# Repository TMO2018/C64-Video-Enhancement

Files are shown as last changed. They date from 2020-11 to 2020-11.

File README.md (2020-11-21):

# C64 Video Enhancement

The original project can be found here:
https://github.com/c0pperdragon

I've made some changes to the VIC II-Adapter pcb and the rfreplacement pcb.

# VIC II-Adapter (A-VideoBoard c64board)
Rev 3.1 is based on c0pperdragons Rev 3
- Fits better with a 407-board
- Layout for hand soldering (SMD 0805)

# rfreplacment
Rev 6.1 is based on c0pperdragons Rev 6
- Layout for hand soldering (SMD 0805)
- Video connector ist placed in the middle of the hole in the C64-housing

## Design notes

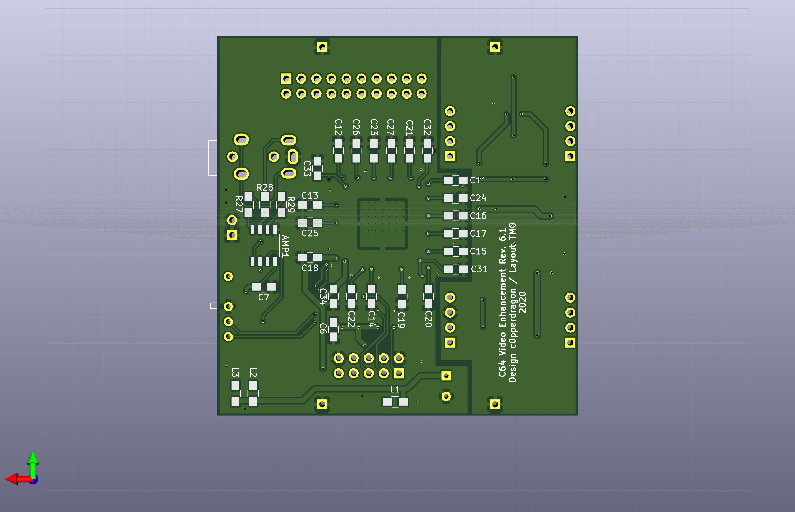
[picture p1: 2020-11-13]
rfreplacement/Rev6_1/pic/rfreplacement_2.jpg

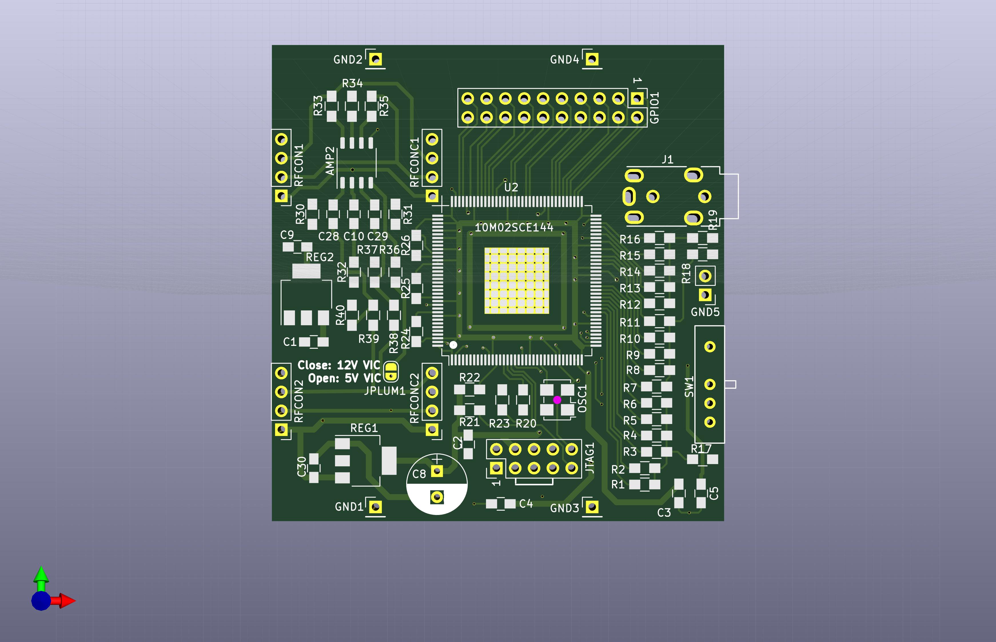
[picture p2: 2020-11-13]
rfreplacement/Rev6_1/pic/rfreplacement_1.jpg

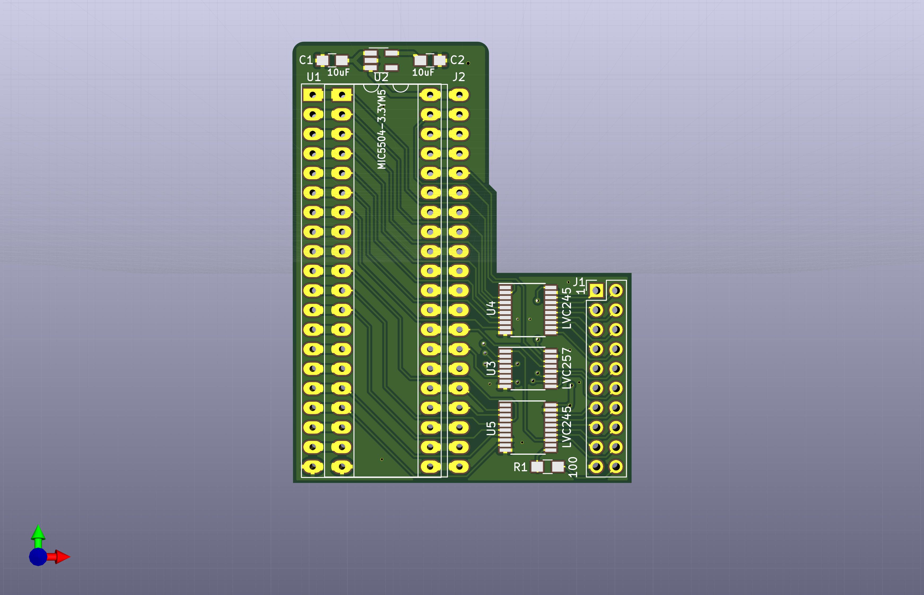
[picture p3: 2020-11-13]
A-VideoBoard c64board/Rev_3_1/pic/c64board_1.jpg

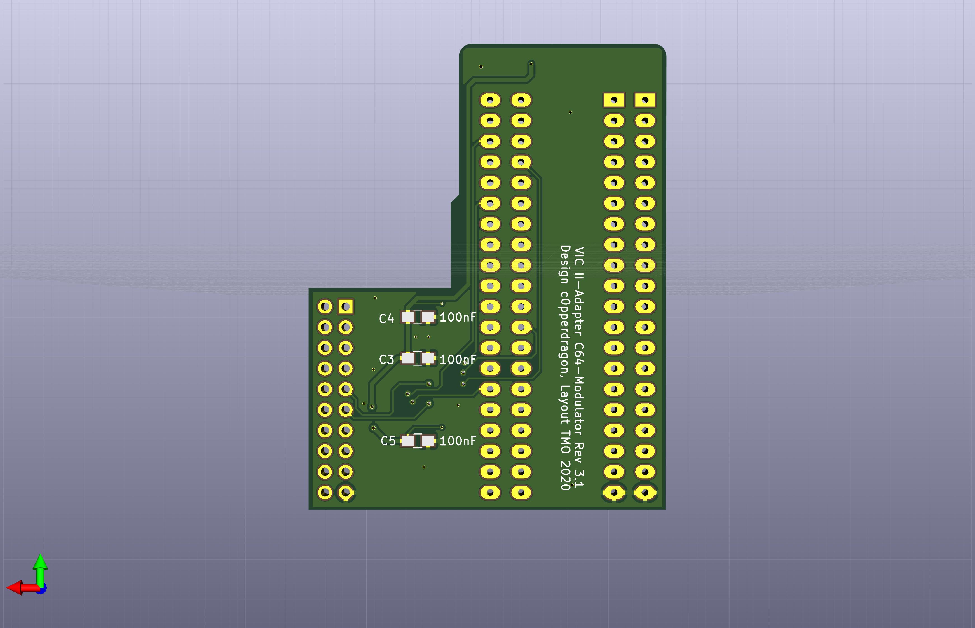
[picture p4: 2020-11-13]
A-VideoBoard c64board/Rev_3_1/pic/c64board_2.jpg

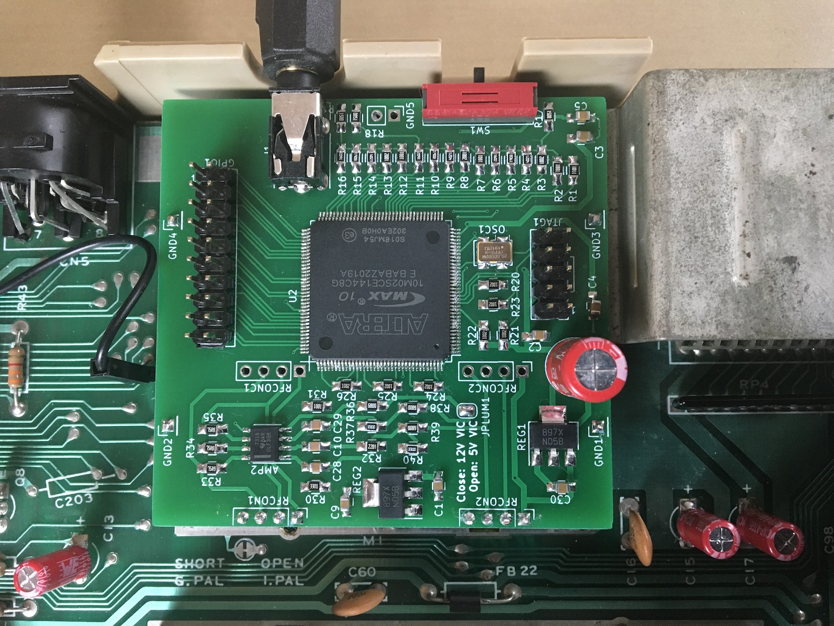
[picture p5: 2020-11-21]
pic/rfreplacement6_1.JPG

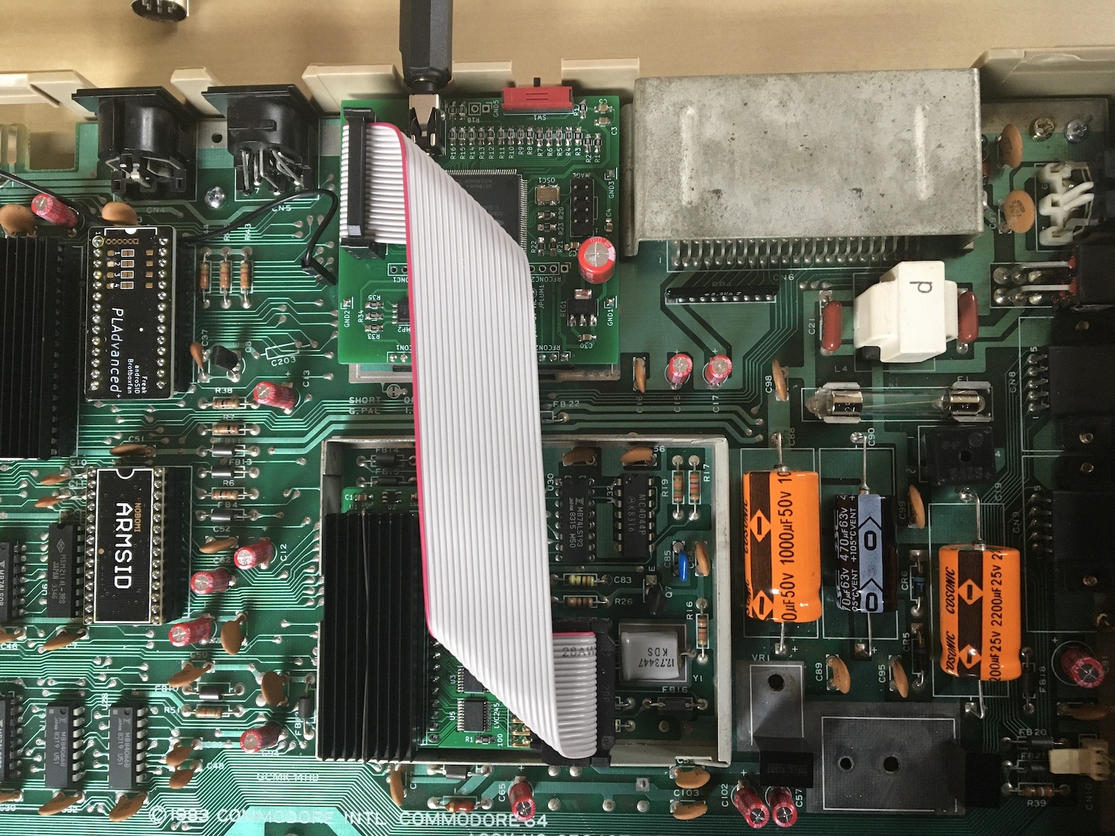
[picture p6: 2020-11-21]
pic/rfreplacement6_1 VICIIboard3_1.jpg

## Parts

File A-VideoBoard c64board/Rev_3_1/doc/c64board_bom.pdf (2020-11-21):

Tabelle1

Manufacturer | Manufacturer Number | Designator | Qty | Description | Case | SMD/ TH | PCB side | Comments
Mill-Max | 111-93-640-41-001000 | U1 | 1 | IC & Component Sockets 40P LONG SOLDER TAIL | | TH | Top | Unusual assembly
Microchip | MIC5504-3.3YM5-TR | U2 | 1 | LDO Voltage Regulators Single 300mA LDO | SOT-23-5 | SMD | Top
Texas Instruments | SN74LVC257APWR | U3 | 1 | Multiplexer | TSSOP-16 | SMD | Top
Texas Instruments | SN74LVC245APWR | U4,U5 | 2 | Bustransceiver Tri-State Octal Bus | TSSOP-20 | SMD | Top
any | | C1,C2 | 2 | Ceramic capacitor 10uF, 10%, 16V | 2012 | SMD | Top
any | | C3,C4,C5 | 3 | Ceramic capacitor 100nF, 10%, 16V | 1608 | SMD | Top
any | | R1 | 1 | Thick film resistor, 100 Ohm, 1% | 2012 | SMD | Top
HARTING | 9181209622 | J1 | 1 | PCB to ribbon cable connector 20P 2 ROW | | TH | Top | Can also be other manufacturer
any | 1 | Ribbon cable, 20 leads, 1,27mm pitch, Length: 13cm | not on PCB
any | 1 | Ribbon cable connector, 20 pins (2x10) female, 2.54mm pitch | not on PCB | gold plated contacts if possible

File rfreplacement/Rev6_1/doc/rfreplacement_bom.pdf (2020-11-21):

Tabelle1

Manufacturer | Manufacturer Number | Designator | Qty | Description | Case | SMD/ TH | PCB side | Comments
Intel | 10M02SCE144C8G | U2 | 1 | FPGA - Field Programmable Gate Array, | 144EQFP | SMD | Top | When hand-soldering: Solder center pad from bottom side
Texas Instruments | THS7316DR | AMP1,AMP2 | 2 | Video Amplifiers 3-Ch HDTV Video Amp | SOIC-8 | SMD | Top
Texas Instruments | LM1117IMPX-3.3/NOPB | REG1,REG2 | 2 | LDO Voltage Regulators 800MA LDO LINEAR REG | SOT-223-4 | SMD | Top
IQD Frequency Products | LFSPXO024957Reel | OSC1 | 1 | Standard Clock Oscillators 25MHz 3.3V 50ppm -40C +85C | 5 mm x 3.2 mm | SMD | Top
NKK Switches | SS14MDH2 | SW1 | 1 | Slide Switches SP3T ON-ON-ON | | TH | Top
Cliff | FC68125 | J1 | 1 | TRRS Jack | | TH | Top
any | | L1,L2,L3 | 3 | Fixed inductors 10uH, 20% | 2012 | SMD | Top
any | | C8 | 1 | Aluminium Electrolytic Capacitor 100uF 16V | 6.3 mm diameter | SMD | Top
any | | C1,C2,C3,C4,C5,C9,C30 | 7 | Ceramic capacitor 10uF, 16V, 20% | 2012 | SMD | Top
any | | C10,C28,C29 | 3 | Ceramic capacitor 100nF, 16V, 20% | 1608 | SMD | Top
any | | C6,C7 | 2 | Ceramic capacitor 100nF, 16V, 20% | 1608 | SMD | Top/Bottom | Bottom until Rev.3, Top from Rev.4 on
any | | C11-C27,C31-C34 | 21 | Ceramic capacitor 100nF, 16V, 20% | 1608 | SMD | Bottom
any | | R27,R28,R29,R33,R34,R35 | 6 | Thick film resistor, 75 Ohm, 1% | 2012 | SMD | Top
any | | R17,R18,R19 | 3 | Thick film resistor, 150 Ohm, 1% | 2012 | SMD | Top
any | | R37,R40 | 2 | Thick film resistor, 330 Ohm, 1% | 2012 | SMD | Top
any | | R36,R38,R39 | 3 | Thick film resistor, 680 Ohm, 1% | 2012 | SMD | Top
any | | R2,R7,R12,R31 | 4 | Thick film resistor, 1k Ohm, 1% | 2012 | SMD | Top
any | | R1 | 1 | Thick film resistor, 1.1k Ohm, 1% | 2012 | SMD | Top
any | | R3,R8,R13 | 3 | Thick film resistor, 2k Ohm, 1% | 2012 | SMD | Top
any | | R32 | 1 | Thick film resistor, 2.2k Ohm, 1% | 2012 | SMD | Top
any | | R30 | 1 | Thick film resistor, 3.3k Ohm, 1% | 2012 | SMD | Top
any | | R4,R9,R14 | 3 | Thick film resistor, 4.02k Ohm, 1% | 2012 | SMD | Top
any | | R5,R10,R15 | 3 | Thick film resistor, 8.06k Ohm, 1% | 2012 | SMD | Top
any | | R6,R11,R16 | 3 | Thick film resistor, 16k Ohm, 1% | 2012 | SMD | Top
any | | R20-R26 | 7 | Thick film resistor, 10k Ohm, 1% | 2012 | SMD | Top
any | | GPIO1 | 1 | Standard pin header, 2x10 pins, 2.54mm , gold plated | | TH | Top
any | | JTAG1 | 1 | Standard pin header, 2x5 pins, 2.54mm, gold plated | | TH | Top

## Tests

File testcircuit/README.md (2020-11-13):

# Test device for the C64 video enhancement mod

In case of a series production of the mod, you probably need some means
to test the mod boards without actually installing them into a real C64.
For this purpose, the necessary input signals can be generated by a 
second FPGA board, programmed to simulate the various VIC signals.
These are fed into the VIC adapter board (via a ZIF socket for example)
which will in turn drive the FPGA board under test to generate the test image.

The provided firmware (TestSignalGenerator.pof) will turn a standard 
C64 video enhanchement board  into a signal generator that uses the GPIO1 port 
and two additional pins as outputs instead of inputs.
Be careful to use such a board only for this test purpose, as
it will cause damage to connect some other signal source to these outputs.

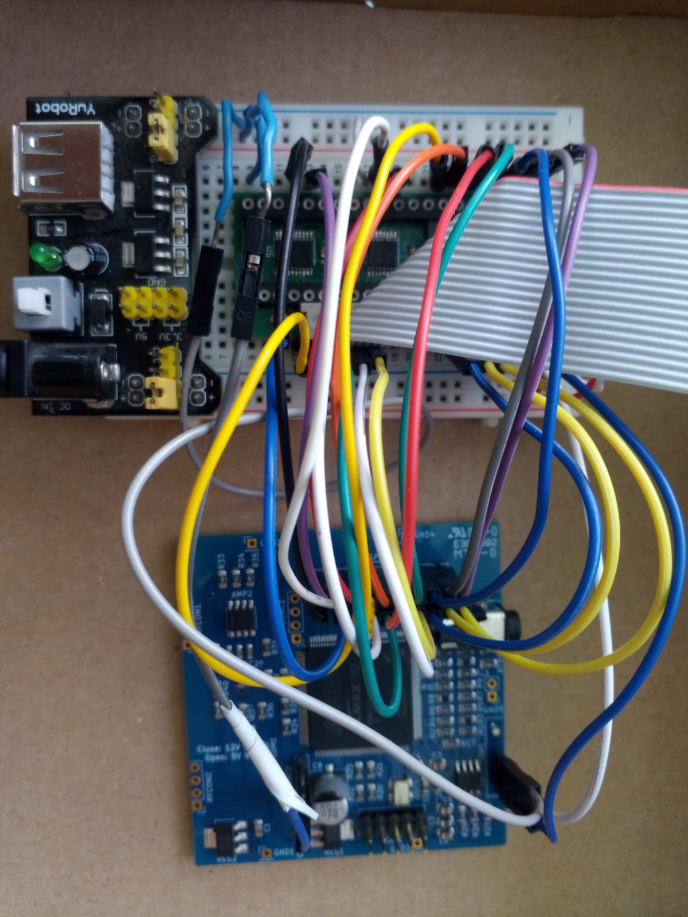
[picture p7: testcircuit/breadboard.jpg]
Experimental setup using a breadboard
	

## Wiring the power 

| Power input  | Signal generator | VIC adapter |
| --- | --- | --- |
| +5V | RFCONC2 1 | Pin 40 |
| GND | SW1 3 | Pin 20 |

## Wiring up the signal generator outputs to the VIC adapter

| FPGA pin | Signal generator | VIC adapter  | Signal |
| --- | --- | --- | --- |
| 74 | GPIO1 1 | Pin 1 | DB6 |
| 76 | GPIO1 3 | Pin 2 | DB5 |
| 78 | GPIO1 5 | Pin 3 | DB4 |
| 80 | GPIO1 7 | Pin 4 | DB3 |
| 87 | GPIO1 9 | Pin 5 | DB2 |
| 91 | GPIO1 11 | Pin 6 | DB1 |
| 97 | GPIO1 13 | Pin 7 | DB0 |
| 99 | GPIO1 15 | Pin 10 | CS |
| 101 | GPIO1 17 | Pin 11 | RW |
| - | GND | Pin 12 | BA (unused) |
| 105 | GPIO1 19 | Pin 16 | AEC |
| 106 | GPIO1 20 | Pin 17 | PHI0 |
| 103 | GPIO1 18 | Pin 24 | A0 |
| 100 | GPIO1 16 | Pin 25 | A1 |
| 98 | GPIO1 14 | Pin 26 | A2 |
| 92 | GPIO1 12 | Pin 27 | A3 |
| 88 | GPIO1 10 | Pin 28 | A4 |
| 81 | GPIO1 8 | Pin 29 | A5 |
| 79 | GPIO1 6 | Pin 35 | DB11 |
| 77 | GPIO1 4 | Pin 36 | DB10 |
| 75 | GPIO1 2 | Pin 37 | DB9 |
| 39 | SW1 1 | Pin 38 | DB8 |
| 40 | SW1 2 | Pin 39 | DB7 |

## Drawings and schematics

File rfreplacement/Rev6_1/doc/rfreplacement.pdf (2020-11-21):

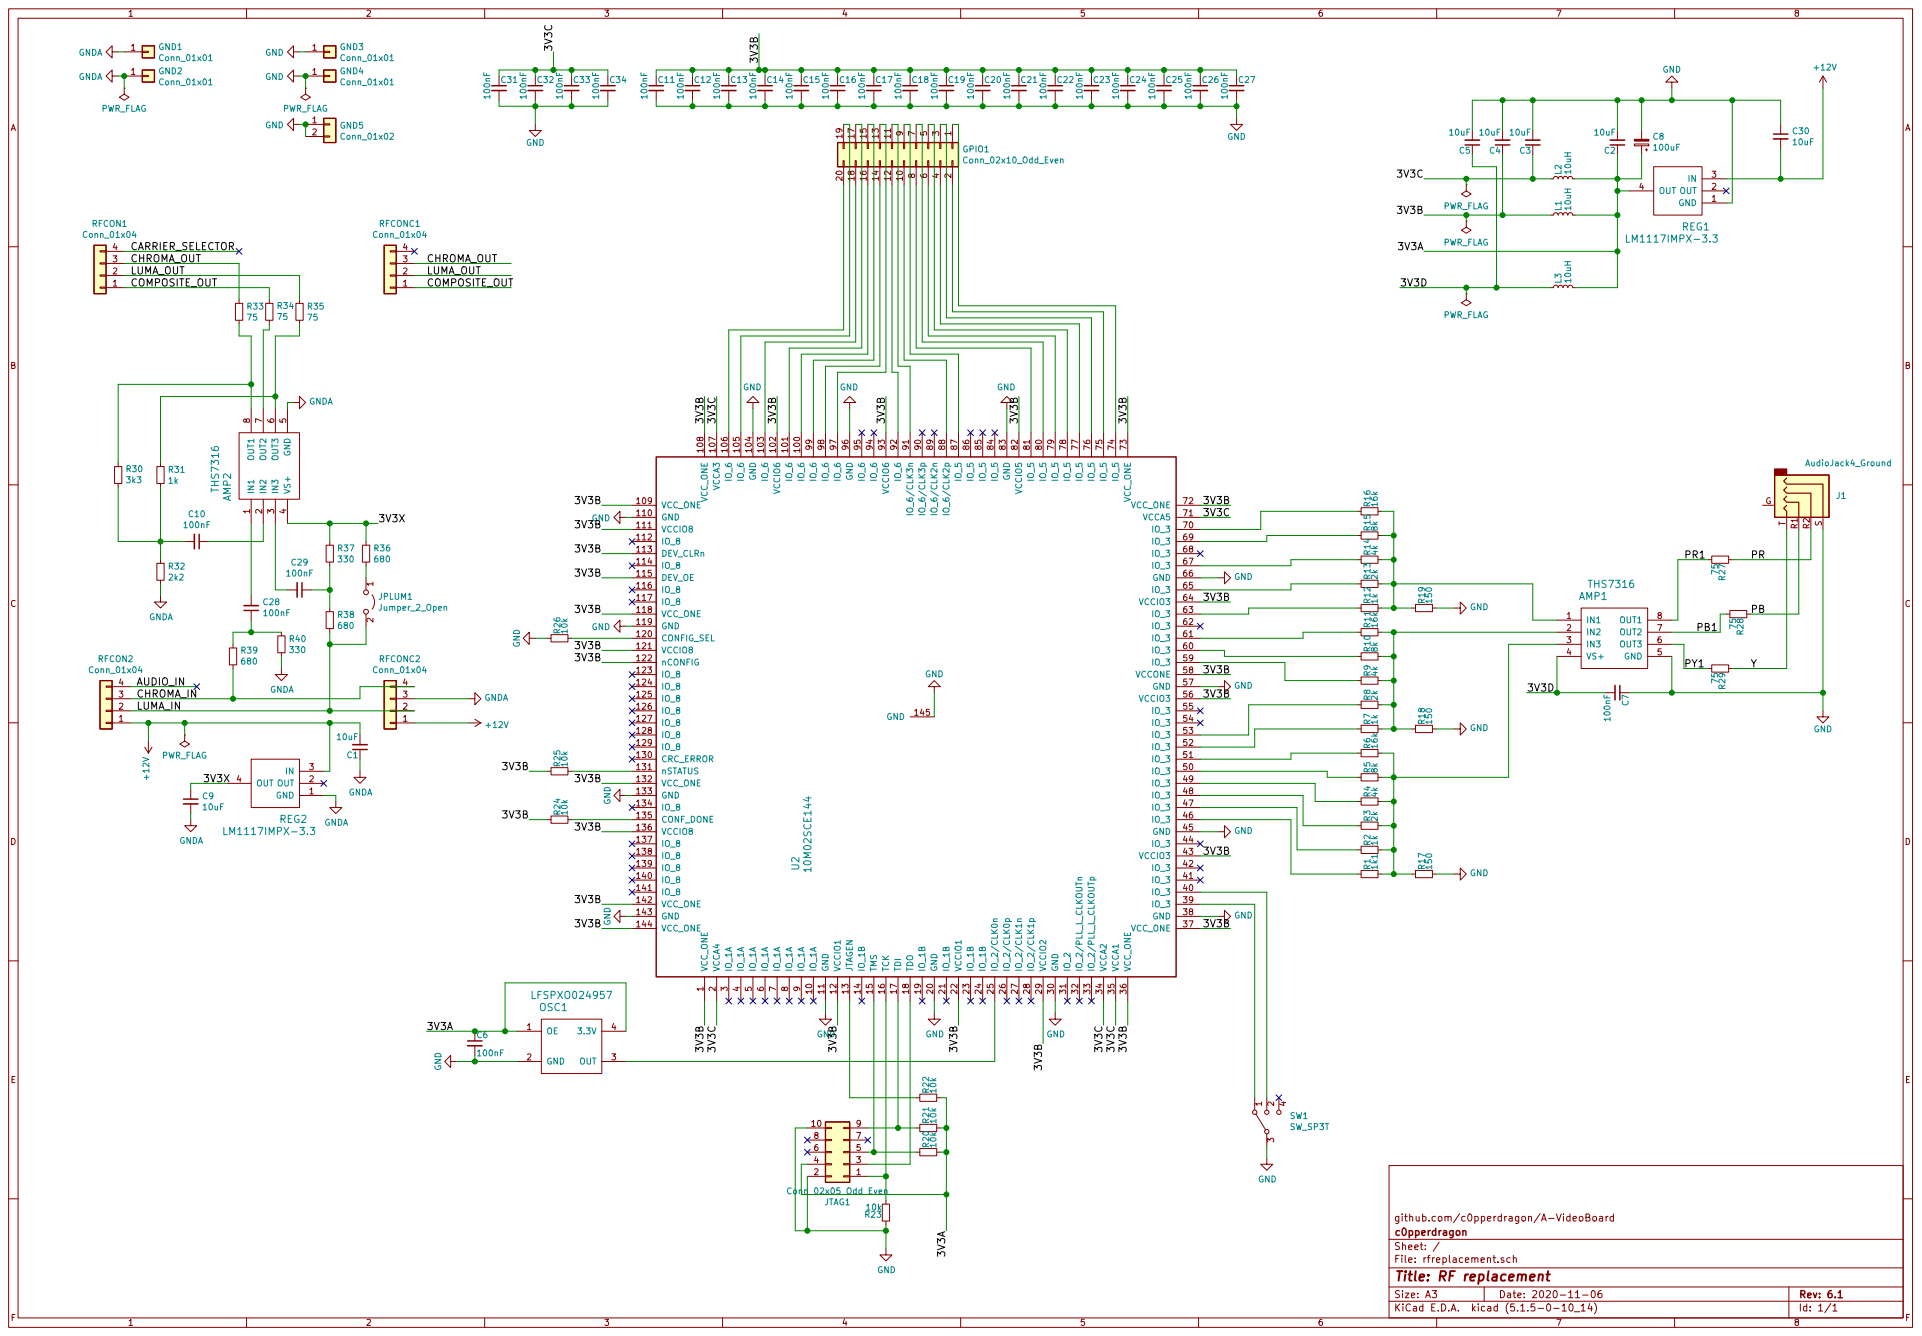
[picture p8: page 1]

1 | 2 1

github.com/c0pperdragon/A-VideoBoard GND

File: rfreplacement.sch Sheet: / c0pperdragon

Id: 1/1 Title: RF replacement

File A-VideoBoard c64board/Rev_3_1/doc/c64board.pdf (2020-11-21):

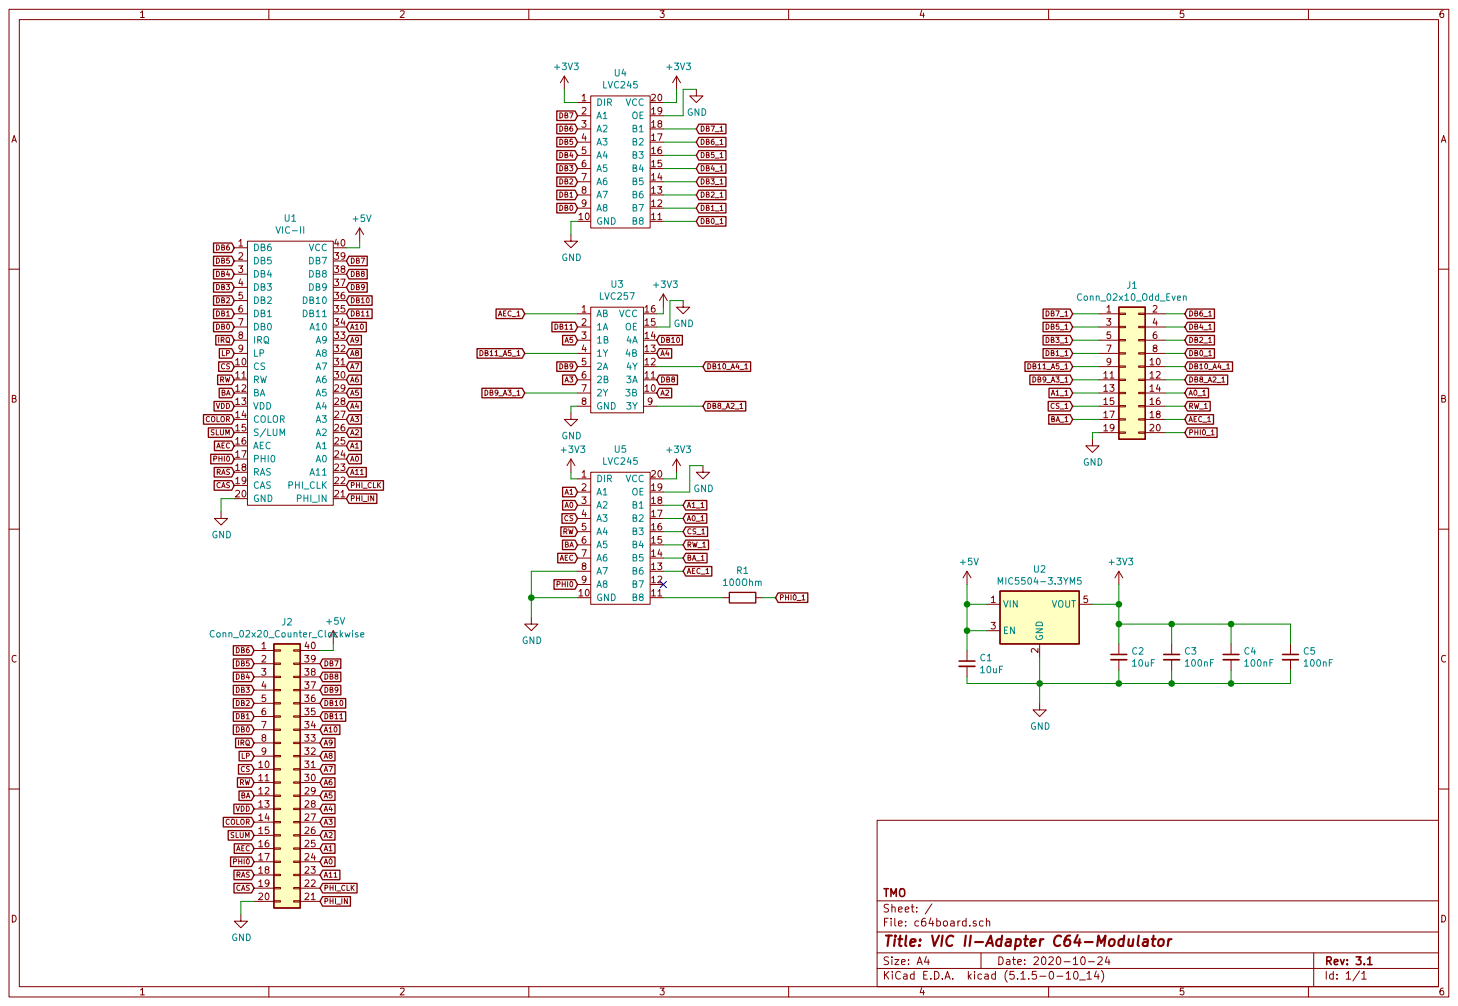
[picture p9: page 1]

Id: 1/1 Title: VIC II-Adapter C64-Modulator File: c64board.sch Sheet: / TMO

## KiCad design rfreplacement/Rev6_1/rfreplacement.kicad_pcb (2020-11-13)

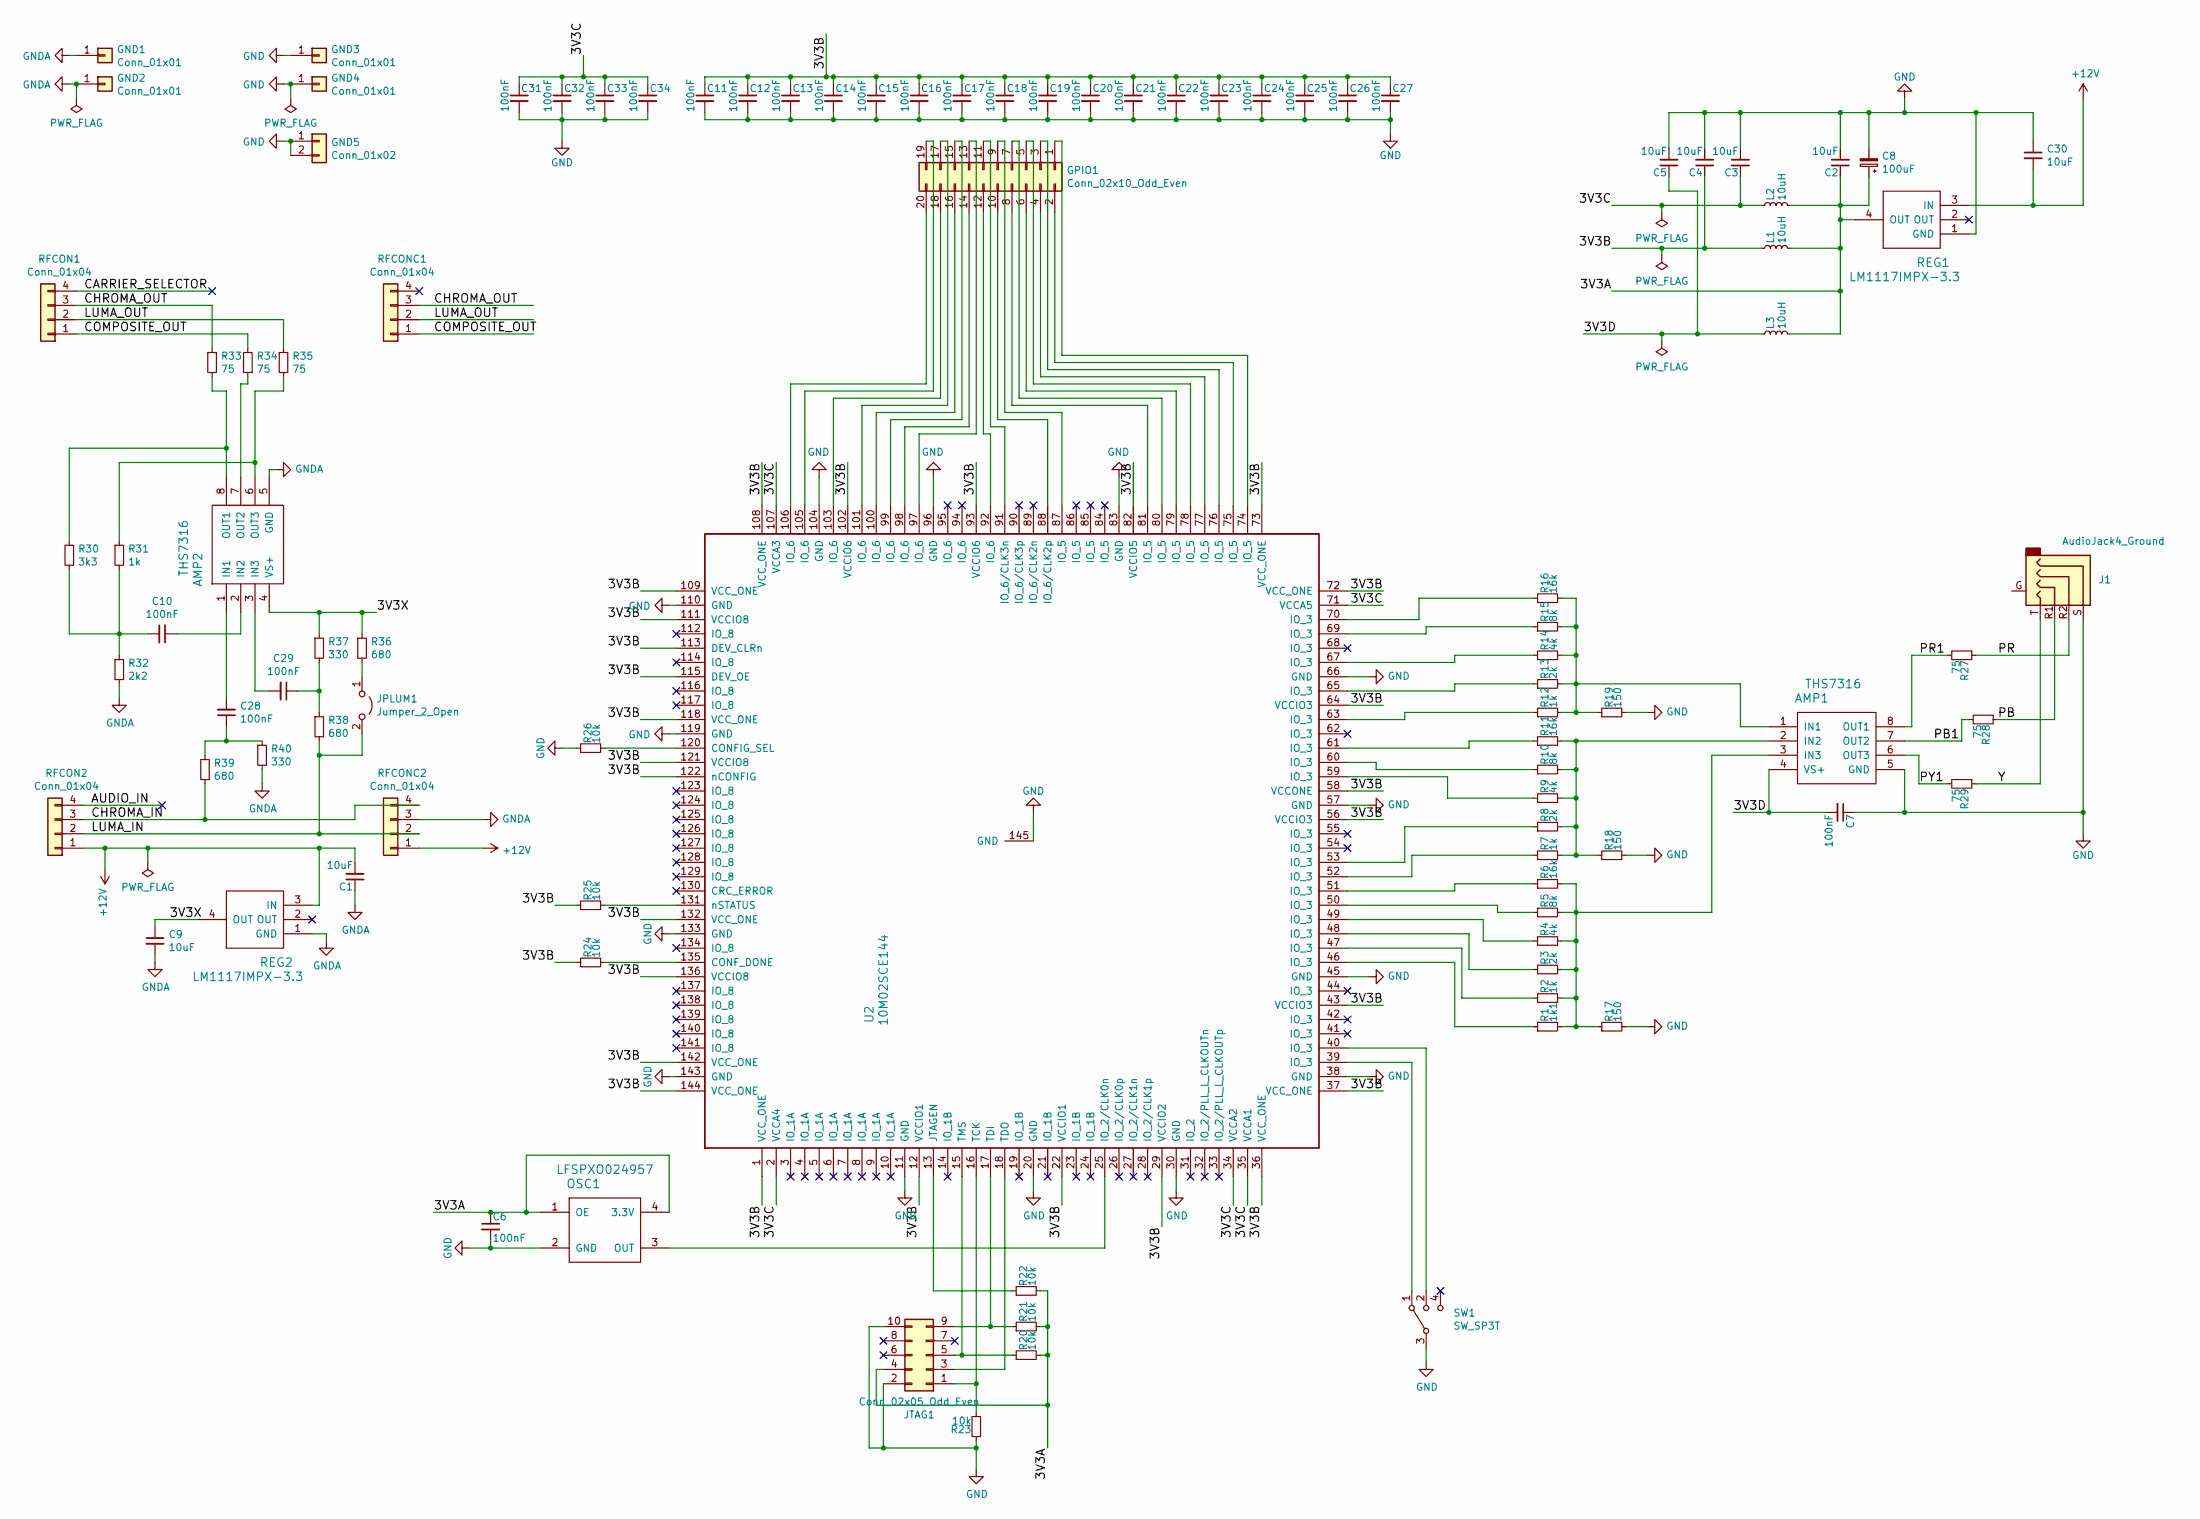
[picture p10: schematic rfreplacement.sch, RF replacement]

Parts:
AMP1, AMP2: THS7316; SSOP-8_3.9x5.05mm_P1.27mm
C1, C2, C3, C4, C5, C9, C30: 10uF; C_0805_HandSoldering
C6, C7, C10, C11, C12, C13, C14, C15, C16, C17, C18, C19, C20, C21, C22, C23, C24, C25, C26, C27, C28, C29, C31, C32, C33, C34: 100nF; C_0805_HandSoldering
C8: 100uF; CP_Radial_D8.0mm_P3.50mm
GND1, GND2, GND3, GND4: Conn_01x01; Pin_Header_Straight_1x01_Pitch2.54mm
GND5: Conn_01x02; Pin_Header_Straight_1x02_Pitch2.54mm
GPIO1: Conn_02x10_Odd_Even; Pin_Header_Straight_2x10_Pitch2.54mm
J1: AudioJack4_Ground; Conrad 4pin audio jack
JPLUM1: Jumper_2_Open; SolderJumper-2_P1.3mm_Open_RoundedPad1.0x1.5mm
JTAG1: Conn_02x05_Odd_Even; Pin_Header_Straight_2x05_Pitch2.54mm
L1, L2, L3: 10uH; L_0805_HandSoldering
OSC1: LFSPXO024957; Oscillator_SMD_EuroQuartz_XO53-4pin_5.0x3.2mm_HandSoldering
R1: 1k1; R_0805_HandSoldering
R2, R7, R12, R31: 1k; R_0805_HandSoldering
R3, R8, R13: 2k; R_0805_HandSoldering
R4, R9, R14: 4k; R_0805_HandSoldering
R5, R10, R15: 8k; R_0805_HandSoldering
R6, R11, R16: 16k; R_0805_HandSoldering
R17, R18, R19: 150; R_0805_HandSoldering
R20, R21, R22, R23, R24, R25, R26: 10k; R_0805_HandSoldering
R27, R28, R29, R33, R34, R35: 75; R_0805_HandSoldering
R30: 3k3; R_0805_HandSoldering
R32: 2k2; R_0805_HandSoldering
R36, R38, R39: 680; R_0805_HandSoldering
R37, R40: 330; R_0805_HandSoldering
REG1, REG2: LM1117IMPX-3.3; SOT-223
RFCON1, RFCON2: Conn_01x04; Pin_Header_Straight_1x04_Pitch2.54mm
RFCONC1, RFCONC2: Conn_01x04; Pin_Header_Straight_1x04_Pitch2.54mm
SW1: SW_SP3T; slider
U2: 10M02SCE144; EQFP-144-1EP_20x20mm_P0.5mm_EP8.93x8.7mm_ThermalVias

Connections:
+12V: C1.2, C30.2, REG1.3 (IN), REG2.3 (IN), RFCON2.1, RFCONC2.1
/3V3A: C2.1, C6.1, C8.1, JTAG1.4, L1.2, L2.2, L3.2, OSC1.1 (OE), OSC1.4 (3.3V), R20.2, R21.2, R22.2, REG1.4 (OUT)
/3V3B: C4.1, C11.1, C12.1, C13.1, C14.1, C15.1, C16.1, C17.1, C18.1, C19.1, C20.1, C21.1, C22.1, C23.1, C24.1, C25.1, C26.1, C27.1, L1.1, R24.1, R25.1, U2.1 (VCC_ONE), U2.12 (VCCIO1), U2.22 (VCCIO1), U2.29 (VCCIO2), U2.36 (VCC_ONE), U2.37 (VCC_ONE), U2.43 (VCCIO3), U2.56 (VCCIO3), U2.58 (VCCONE), U2.64 (VCCIO3), U2.72 (VCC_ONE), U2.73 (VCC_ONE), U2.82 (VCCIO5), U2.93 (VCCIO6), U2.102 (VCCIO6), U2.108 (VCC_ONE), U2.109 (VCC_ONE), U2.111 (VCCIO8), U2.113 (DEV_CLRn), U2.115 (DEV_OE), U2.118 (VCC_ONE), U2.121 (VCCIO8), U2.122 (nCONFIG), U2.132 (VCC_ONE), U2.136 (VCCIO8), U2.142 (VCC_ONE), U2.144 (VCC_ONE)
/3V3C: C3.1, C31.1, C32.1, C33.1, C34.1, L2.1, U2.2 (VCCA4), U2.34 (VCCA2), U2.35 (VCCA1), U2.71 (VCCA5), U2.107 (VCCA3)
/3V3D: AMP1.4 (VS+), C5.1, C7.2, L3.1
/3V3X: AMP2.4 (VS+), C9.1, R36.1, R37.1, REG2.4 (OUT)
/CHROMA_IN: R39.1, RFCON2.3, RFCONC2.4
/CHROMA_OUT: R33.1, RFCON1.3, RFCONC1.3
/COMPOSITE_OUT: R34.2, RFCON1.1, RFCONC1.1
/LUMA_IN: JPLUM1.2 (B), R38.2, RFCON2.2, RFCONC2.2
/LUMA_OUT: R35.1, RFCON1.2, RFCONC1.2
/PB: J1.R1, R28.1
/PB1: AMP1.7 (OUT2), R28.2
/PR: J1.R2, R27.1
/PR1: AMP1.8 (OUT1), R27.2
/PY1: AMP1.6 (OUT3), R29.2
/Y: J1.T, R29.1
GND: AMP1.5 (GND), C2.2, C3.2, C4.2, C5.2, C6.2, C7.1, C8.2, C11.2, C12.2, C13.2, C14.2, C15.2, C16.2, C17.2, C18.2, C19.2, C20.2, C21.2, C22.2, C23.2, C24.2, C25.2, C26.2, C27.2, C30.1, C31.2, C32.2, C33.2, C34.2, GND3.1, GND4.1, GND5.1, GND5.2, J1.S, JTAG1.2, JTAG1.10, OSC1.2 (GND), R17.2, R18.2, R19.2, R23.1, R26.1, REG1.1 (GND), SW1.3, U2.11 (GND), U2.20 (GND), U2.30 (GND), U2.38 (GND), U2.45 (GND), U2.57 (GND), U2.66 (GND), U2.83 (GND), U2.96 (GND), U2.104 (GND), U2.110 (GND), U2.119 (GND), U2.133 (GND), U2.143 (GND), U2.145 (GND)
GNDA: AMP2.5 (GND), C1.1, C9.2, GND1.1, GND2.1, R32.2, R40.2, REG2.1 (GND), RFCONC2.3
unnamed: AMP1.1 (IN1), R12.2, R13.2, R14.2, R15.2, R16.2, R19.1
unnamed: AMP1.2 (IN2), R7.2, R8.2, R9.2, R10.2, R11.2, R18.1
unnamed: AMP1.3 (IN3), R1.2, R2.2, R3.2, R4.2, R5.2, R6.2, R17.1
unnamed: AMP2.1 (IN1), C28.2
unnamed: AMP2.2 (IN2), C10.1
unnamed: AMP2.3 (IN3), C29.2
unnamed: AMP2.6 (OUT3), R31.1, R35.2
unnamed: AMP2.7 (OUT2), R34.1
unnamed: AMP2.8 (OUT1), R30.2, R33.2
unnamed: C10.2, R30.1, R31.2, R32.1
unnamed: C28.1, R39.2, R40.1
unnamed: C29.1, R37.2, R38.1
unnamed: GPIO1.1, U2.74 (IO_5)
unnamed: GPIO1.2, U2.75 (IO_5)
unnamed: GPIO1.3, U2.76 (IO_5)
unnamed: GPIO1.4, U2.77 (IO_5)
unnamed: GPIO1.5, U2.78 (IO_5)
unnamed: GPIO1.6, U2.79 (IO_5)
unnamed: GPIO1.7, U2.80 (IO_5)
unnamed: GPIO1.8, U2.81 (IO_5)
unnamed: GPIO1.9, U2.87 (IO_5)
unnamed: GPIO1.10, U2.88 (IO_6/CLK2p)
unnamed: GPIO1.11, U2.91 (IO_6/CLK3n)
unnamed: GPIO1.12, U2.92 (IO_6)
unnamed: GPIO1.13, U2.97 (IO_6)
unnamed: GPIO1.14, U2.98 (IO_6)
unnamed: GPIO1.15, U2.99 (IO_6)
unnamed: GPIO1.16, U2.100 (IO_6)
unnamed: GPIO1.17, U2.101 (IO_6)
unnamed: GPIO1.18, U2.103 (IO_6)
unnamed: GPIO1.19, U2.105 (IO_6)
unnamed: GPIO1.20, U2.106 (IO_6)
unnamed: JPLUM1.1 (A), R36.2
unnamed: JTAG1.1, R23.2, U2.16 (TCK)
unnamed: JTAG1.3, U2.18 (TDO)
unnamed: JTAG1.5, R20.1, U2.15 (TMS)
unnamed: JTAG1.9, R21.1, U2.17 (TDI)
unnamed: OSC1.3 (OUT), U2.25 (IO_2/CLK0n)
unnamed: R1.1, U2.46 (IO_3)
unnamed: R2.1, U2.47 (IO_3)
unnamed: R3.1, U2.48 (IO_3)
unnamed: R4.1, U2.49 (IO_3)
unnamed: R5.1, U2.50 (IO_3)
unnamed: R6.1, U2.51 (IO_3)
unnamed: R7.1, U2.52 (IO_3)
unnamed: R8.1, U2.53 (IO_3)
unnamed: R9.1, U2.59 (IO_3)
unnamed: R10.1, U2.60 (IO_3)
unnamed: R11.1, U2.61 (IO_3)
unnamed: R12.1, U2.63 (IO_3)
unnamed: R13.1, U2.65 (IO_3)
unnamed: R14.1, U2.67 (IO_3)
unnamed: R15.1, U2.69 (IO_3)
unnamed: R16.1, U2.70 (IO_3)
unnamed: R22.1, U2.13 (JTAGEN)
unnamed: R24.2, U2.135 (CONF_DONE)
unnamed: R25.2, U2.131 (nSTATUS)
unnamed: R26.2, U2.120 (CONFIG_SEL)
unnamed: SW1.1, U2.39 (IO_3)
unnamed: SW1.2, U2.40 (IO_3)

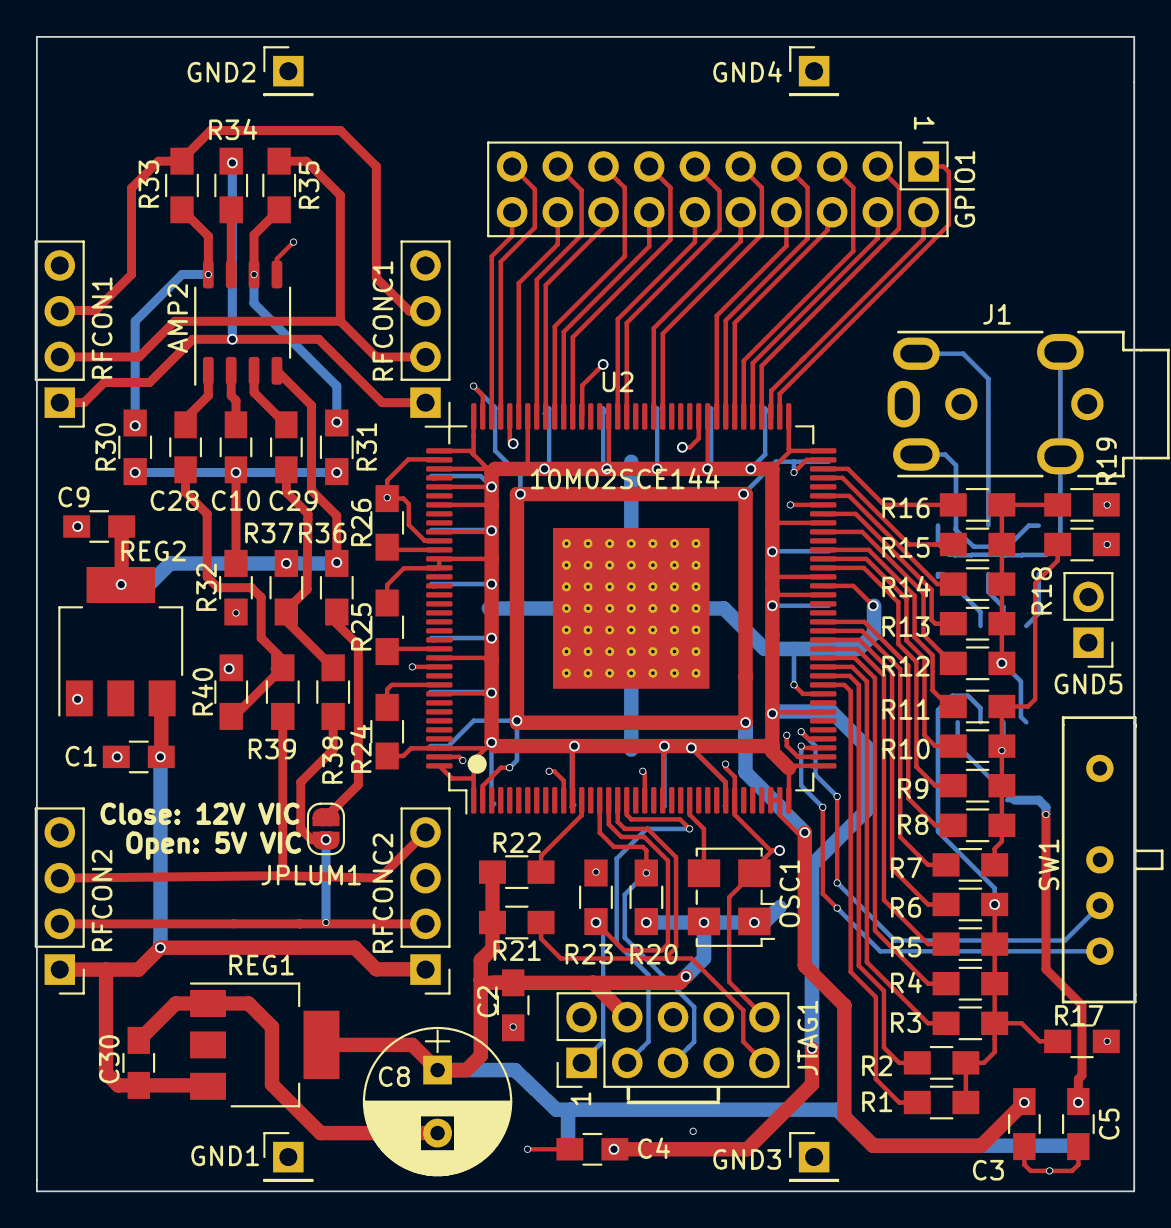
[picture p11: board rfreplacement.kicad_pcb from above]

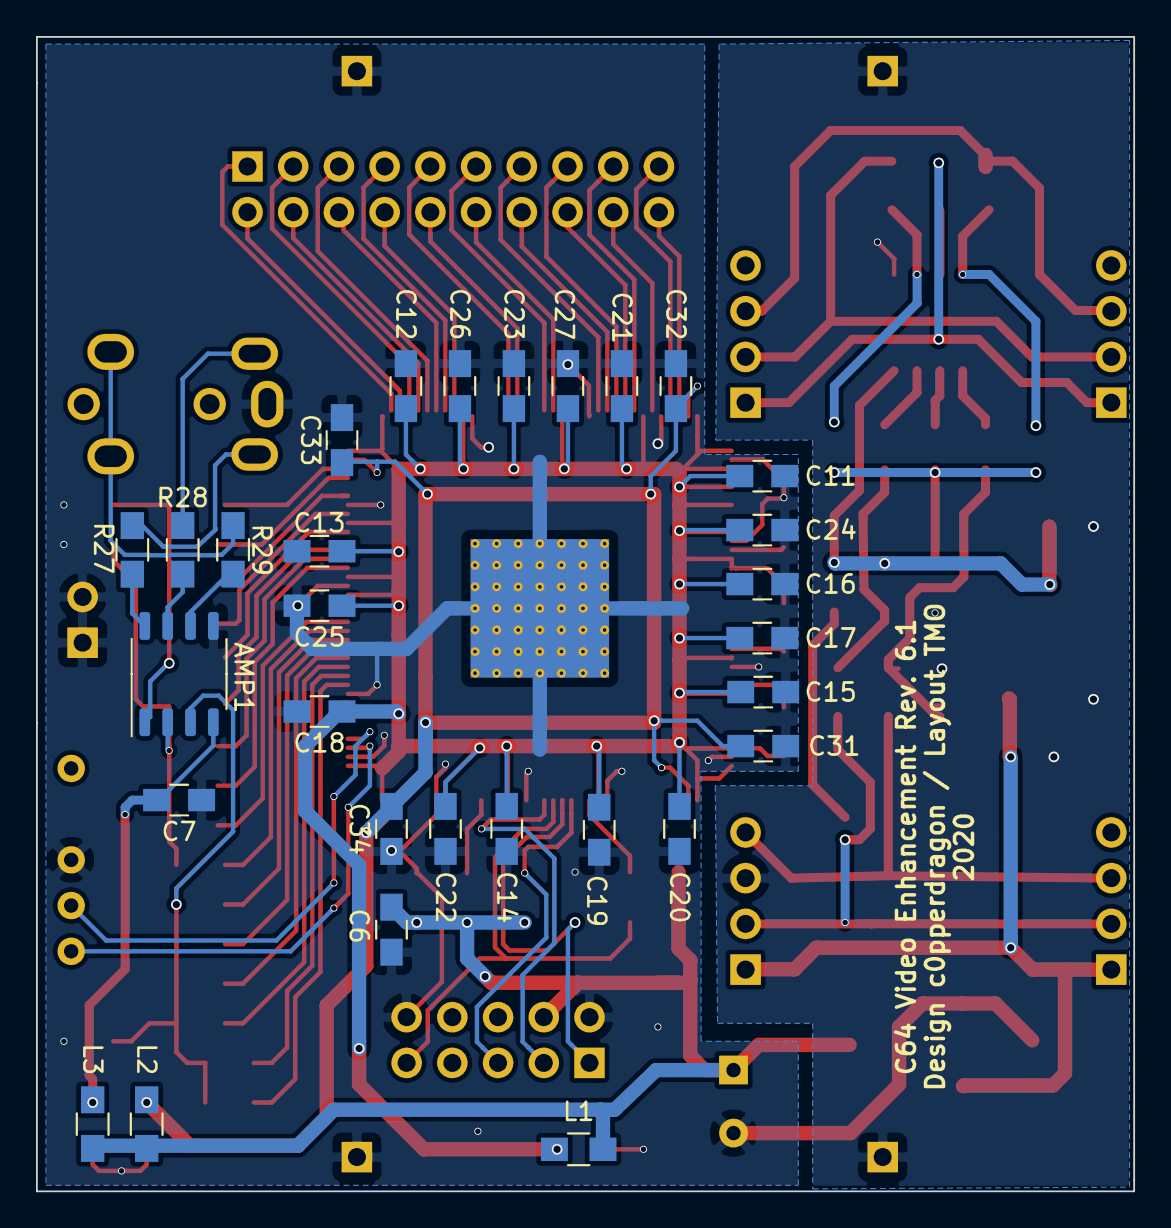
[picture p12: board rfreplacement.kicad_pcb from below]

Board: 2 copper layers, 61.0 x 64.1 mm, 97 parts (30 on the bottom side), 79 nets.

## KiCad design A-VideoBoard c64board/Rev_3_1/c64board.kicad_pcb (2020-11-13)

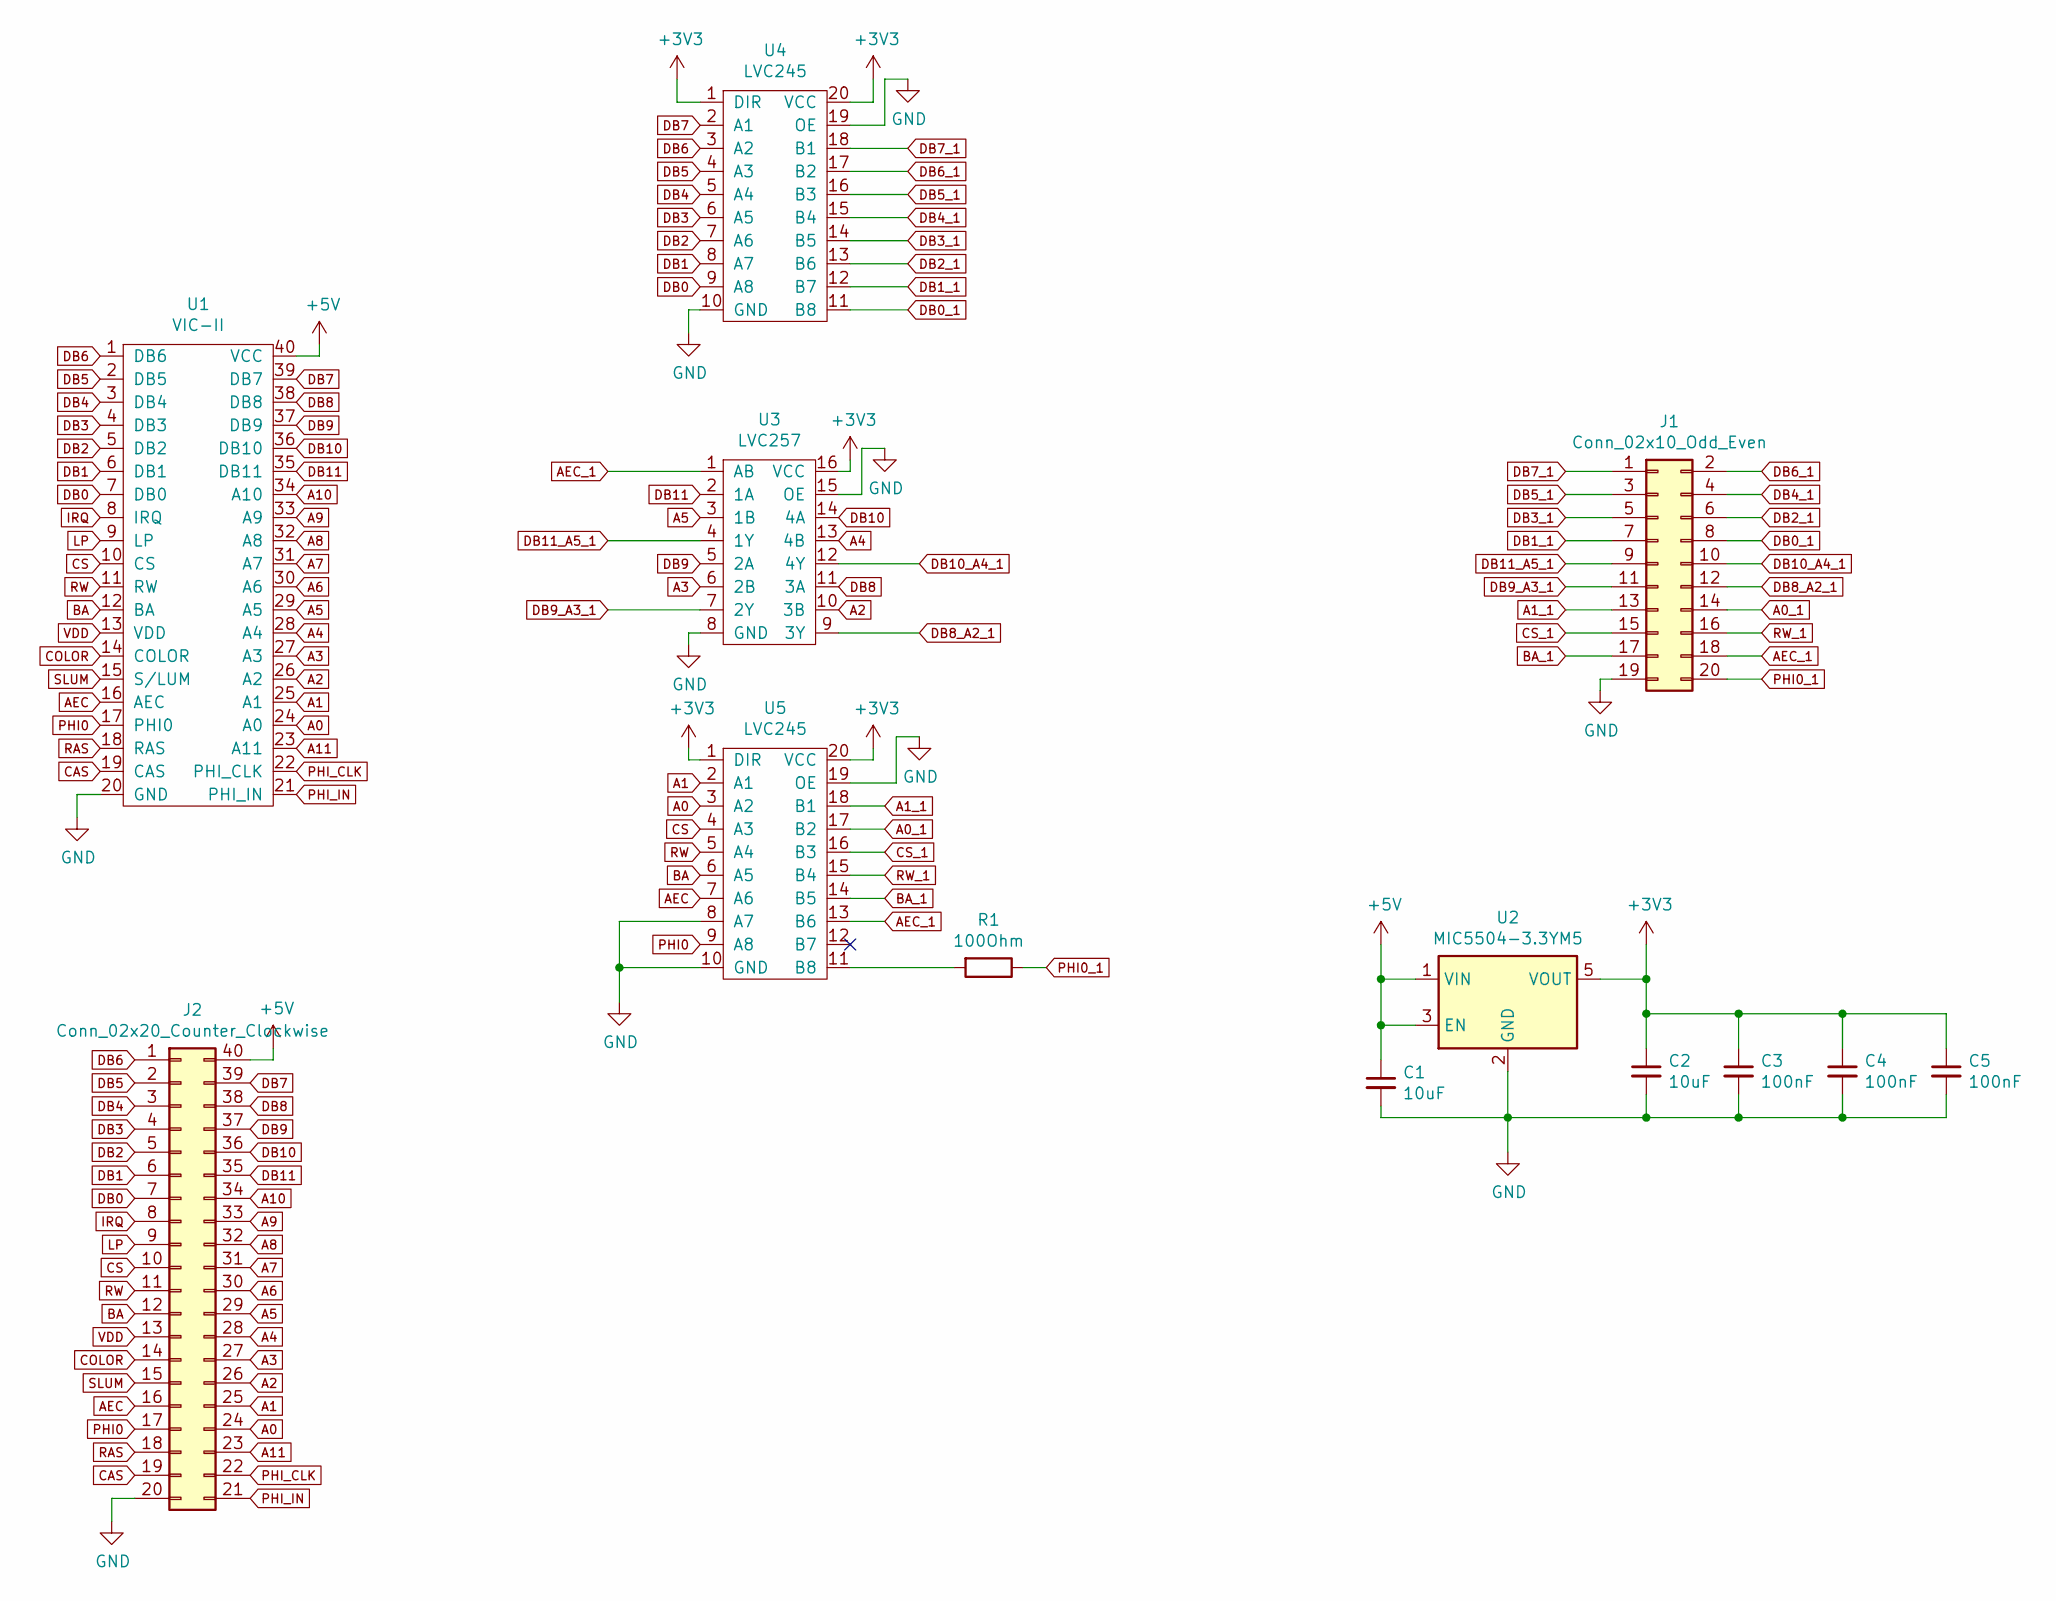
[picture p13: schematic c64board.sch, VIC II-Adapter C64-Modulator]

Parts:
C1, C2: 10uF; C_0805_HandSoldering
C3, C4, C5: 100nF; C_0805_HandSoldering
J1: Conn_02x10_Odd_Even; Pin_Header_Straight_2x10_Pitch2.54mm
J2: Conn_02x20_Counter_Clockwise; DIP-40_W15.24mm_LongPads
R1: 100Ohm; R_0805_HandSoldering
U1: VIC-II; DIP-40_W15.24mm_Socket_LongPads
U2: MIC5504-3.3YM5; SOT-23-5_HandSoldering
U3: LVC257; TSSOP-16_4.4x5mm_Pitch0.65mm
U4, U5: LVC245; TSSOP-20_4.4x6.5mm_Pitch0.65mm

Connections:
+3V3: C2.1, C3.1, C4.1, C5.1, U2.5 (VOUT), U3.16 (VCC), U4.1 (DIR), U4.20 (VCC), U5.1 (DIR), U5.20 (VCC)
+5V: C1.1, J2.40, U1.40 (VCC), U2.1 (VIN), U2.3 (EN)
A0: J2.24, U1.24 (A0), U5.3 (A2)
A0_1: J1.14, U5.17 (B2)
A1: J2.25, U1.25 (A1), U5.2 (A1)
A1_1: J1.13, U5.18 (B1)
A2: J2.26, U1.26 (A2), U3.10 (3B)
A3: J2.27, U1.27 (A3), U3.6 (2B)
A4: J2.28, U1.28 (A4), U3.13 (4B)
A5: J2.29, U1.29 (A5), U3.3 (1B)
A6: J2.30, U1.30 (A6)
A7: J2.31, U1.31 (A7)
A8: J2.32, U1.32 (A8)
A9: J2.33, U1.33 (A9)
A10: J2.34, U1.34 (A10)
A11: J2.23, U1.23 (A11)
AEC: J2.16, U1.16 (AEC), U5.7 (A6)
AEC_1: J1.18, U3.1 (AB), U5.13 (B6)
BA: J2.12, U1.12 (BA), U5.6 (A5)
BA_1: J1.17, U5.14 (B5)
CAS: J2.19, U1.19 (CAS)
COLOR: J2.14, U1.14 (COLOR)
CS: J2.10, U1.10 (CS), U5.4 (A3)
CS_1: J1.15, U5.16 (B3)
DB0: J2.7, U1.7 (DB0), U4.9 (A8)
DB0_1: J1.8, U4.11 (B8)
DB1: J2.6, U1.6 (DB1), U4.8 (A7)
DB1_1: J1.7, U4.12 (B7)
DB2: J2.5, U1.5 (DB2), U4.7 (A6)
DB2_1: J1.6, U4.13 (B6)
DB3: J2.4, U1.4 (DB3), U4.6 (A5)
DB3_1: J1.5, U4.14 (B5)
DB4: J2.3, U1.3 (DB4), U4.5 (A4)
DB4_1: J1.4, U4.15 (B4)
DB5: J2.2, U1.2 (DB5), U4.4 (A3)
DB5_1: J1.3, U4.16 (B3)
DB6: J2.1, U1.1 (DB6), U4.3 (A2)
DB6_1: J1.2, U4.17 (B2)
DB7: J2.39, U1.39 (DB7), U4.2 (A1)
DB7_1: J1.1, U4.18 (B1)
DB8: J2.38, U1.38 (DB8), U3.11 (3A)
DB8_A2_1: J1.12, U3.9 (3Y)
DB9: J2.37, U1.37 (DB9), U3.5 (2A)
DB9_A3_1: J1.11, U3.7 (2Y)
DB10: J2.36, U1.36 (DB10), U3.14 (4A)
DB10_A4_1: J1.10, U3.12 (4Y)
DB11: J2.35, U1.35 (DB11), U3.2 (1A)
DB11_A5_1: J1.9, U3.4 (1Y)
GND: C1.2, C2.2, C3.2, C4.2, C5.2, J1.19, J2.20, U1.20 (GND), U2.2 (GND), U3.8 (GND), U3.15 (OE), U4.10 (GND), U4.19 (OE), U5.8 (A7), U5.10 (GND), U5.19 (OE)
IRQ: J2.8, U1.8 (IRQ)
LP: J2.9, U1.9 (LP)
unnamed: R1.2, U5.11 (B8)
PHI0: J2.17, U1.17 (PHI0), U5.9 (A8)
PHI0_1: J1.20, R1.1
PHI_CLK: J2.22, U1.22 (PHI_CLK)
PHI_IN: J2.21, U1.21 (PHI_IN)
RAS: J2.18, U1.18 (RAS)
RW: J2.11, U1.11 (RW), U5.5 (A4)
RW_1: J1.16, U5.15 (B4)
SLUM: J2.15, U1.15 (S/LUM)
VDD: J2.13, U1.13 (VDD)

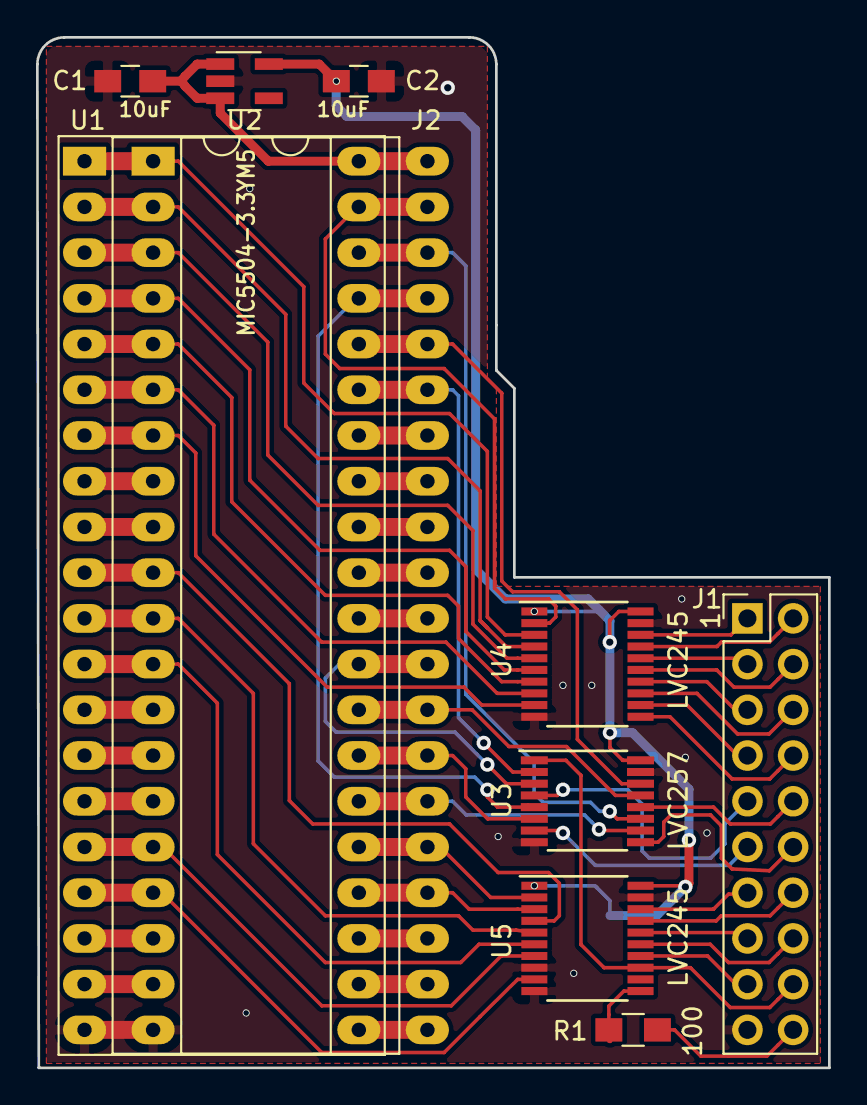
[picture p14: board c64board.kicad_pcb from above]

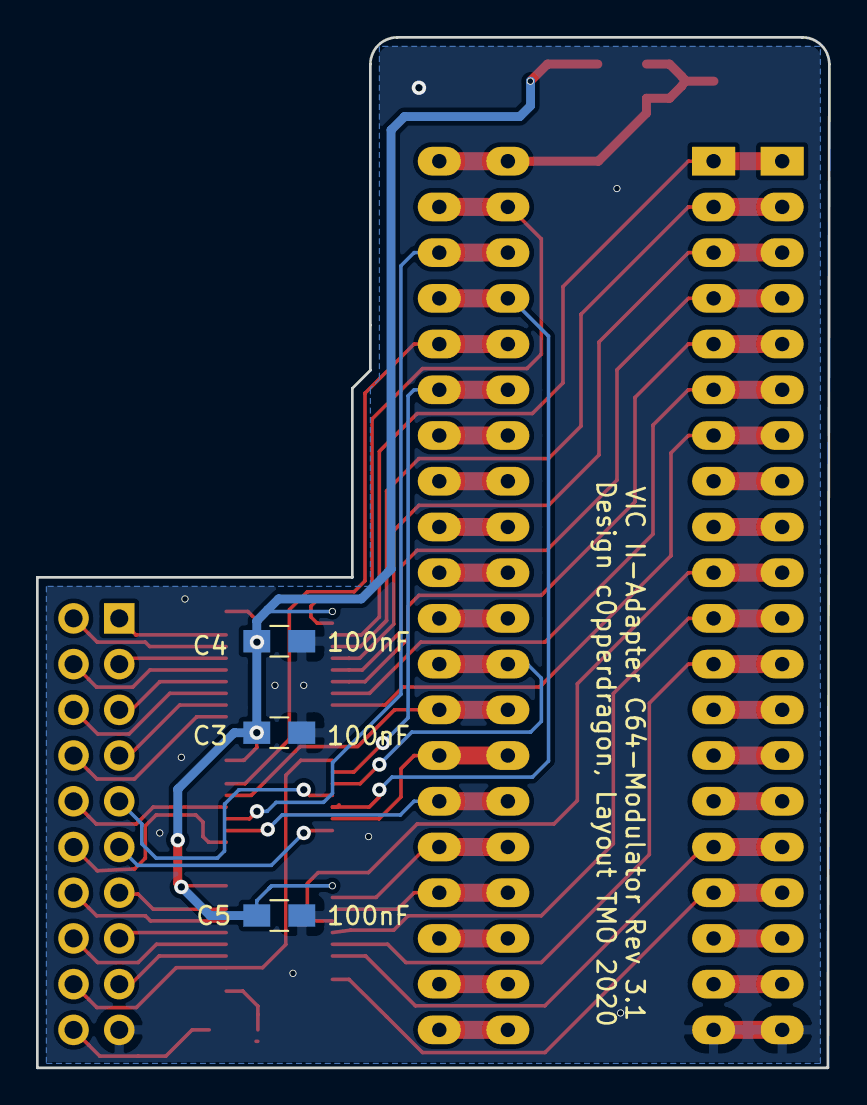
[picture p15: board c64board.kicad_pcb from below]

Board: 2 copper layers, 44.0 x 57.2 mm, 13 parts (3 on the bottom side), 61 nets.
